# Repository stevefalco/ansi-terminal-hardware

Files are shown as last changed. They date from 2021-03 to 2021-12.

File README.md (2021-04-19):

ANSI Terminal is a "dumb" terminal that emulates part of a VT100.  It is sufficient to use with vi under 2.11bsd, and it also works well as a dumb terminal for Linux.  It successfully allows editing using the "vim" editor.  An M68K (M68000) soft-core processor is contained in an FPGA on a CYC1000 module, and handles all the processing chores.

This project contains IP cores as follows:

https://github.com/ijor/fx68k provides the M68000 processor.

https://opencores.org/projects/a_vhd_16550_uart provides a 16550 compatible uart.

Unlike many existing terminal projects, this project targets 1280x1024 monitors, which are much more common than the 640x480 monitors of days gone by.  This also allows higher quality characters, using 16x32 glyphs, rather than the more common 8x16 glyphs.

The terminal supports both hardware and software flow control, as selected by a dip switch, and baud rates from 110 to 115200 are supported.

This project contains the KiCAD schematic, board layout, gerbers, and a 3-D printable case design.  Note that this is a 2-layer board with surface mount components.

A companion project, https://github.com/stevefalco/ansi-terminal-firmware contains the FPGA and assembly language software for the ANSI Terminal.

Here are photos of the case, pcb, schematic and displayed text.  There is a higher resolution copy of the schematic in file terminal.pdf.

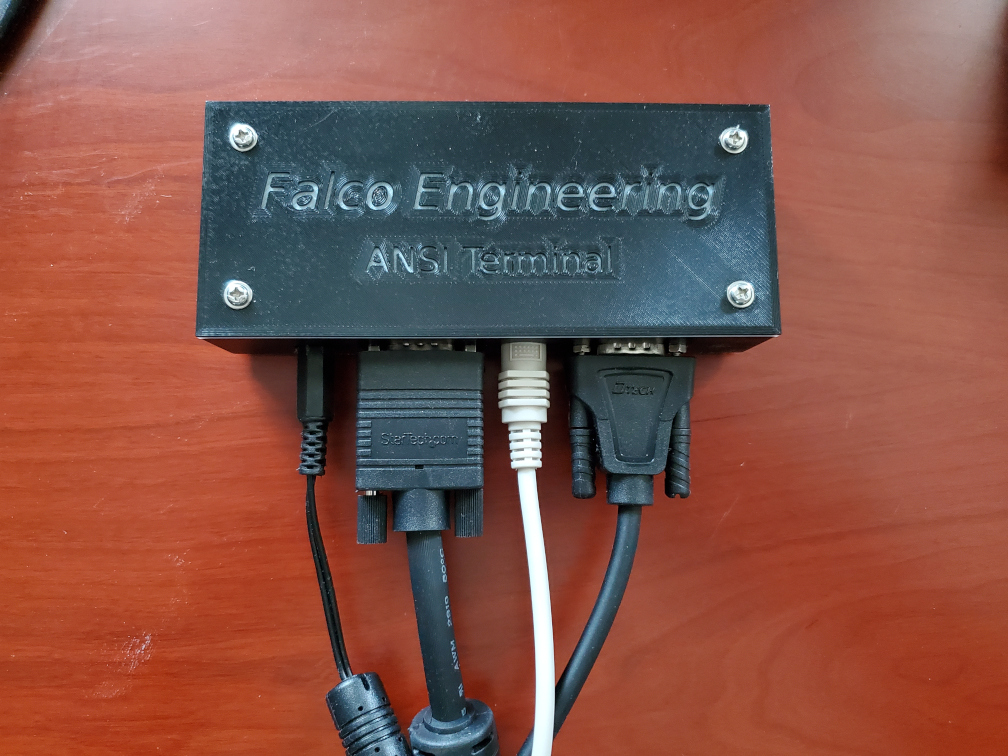
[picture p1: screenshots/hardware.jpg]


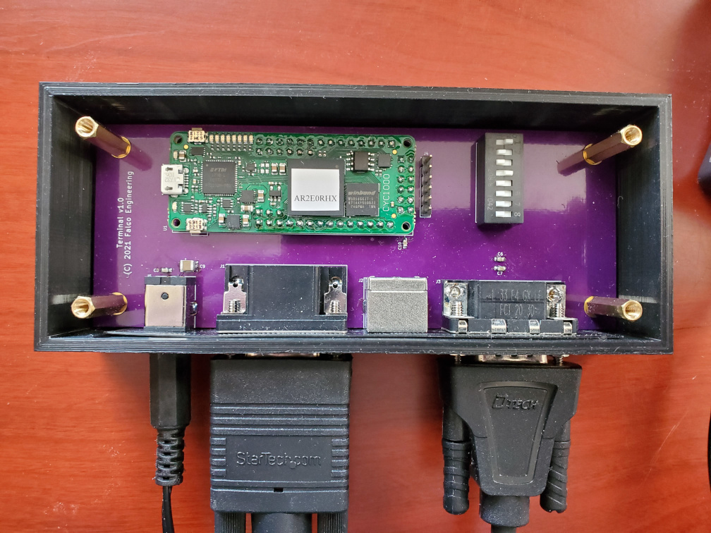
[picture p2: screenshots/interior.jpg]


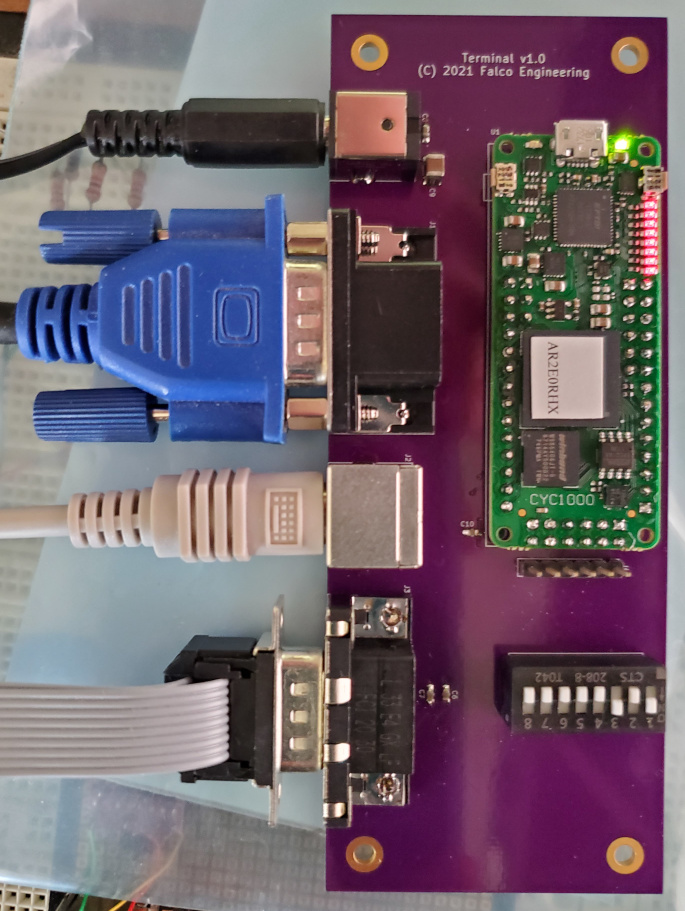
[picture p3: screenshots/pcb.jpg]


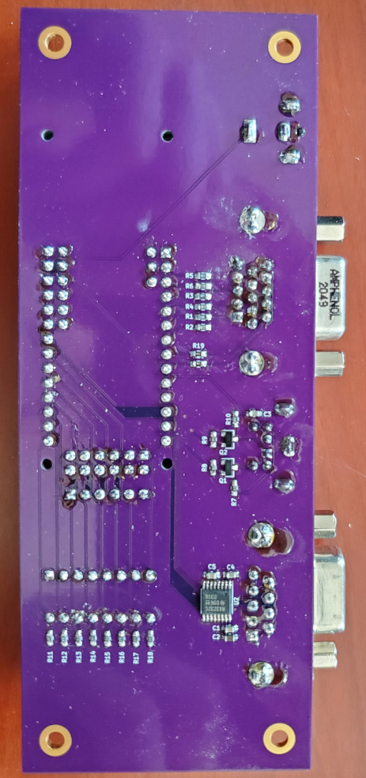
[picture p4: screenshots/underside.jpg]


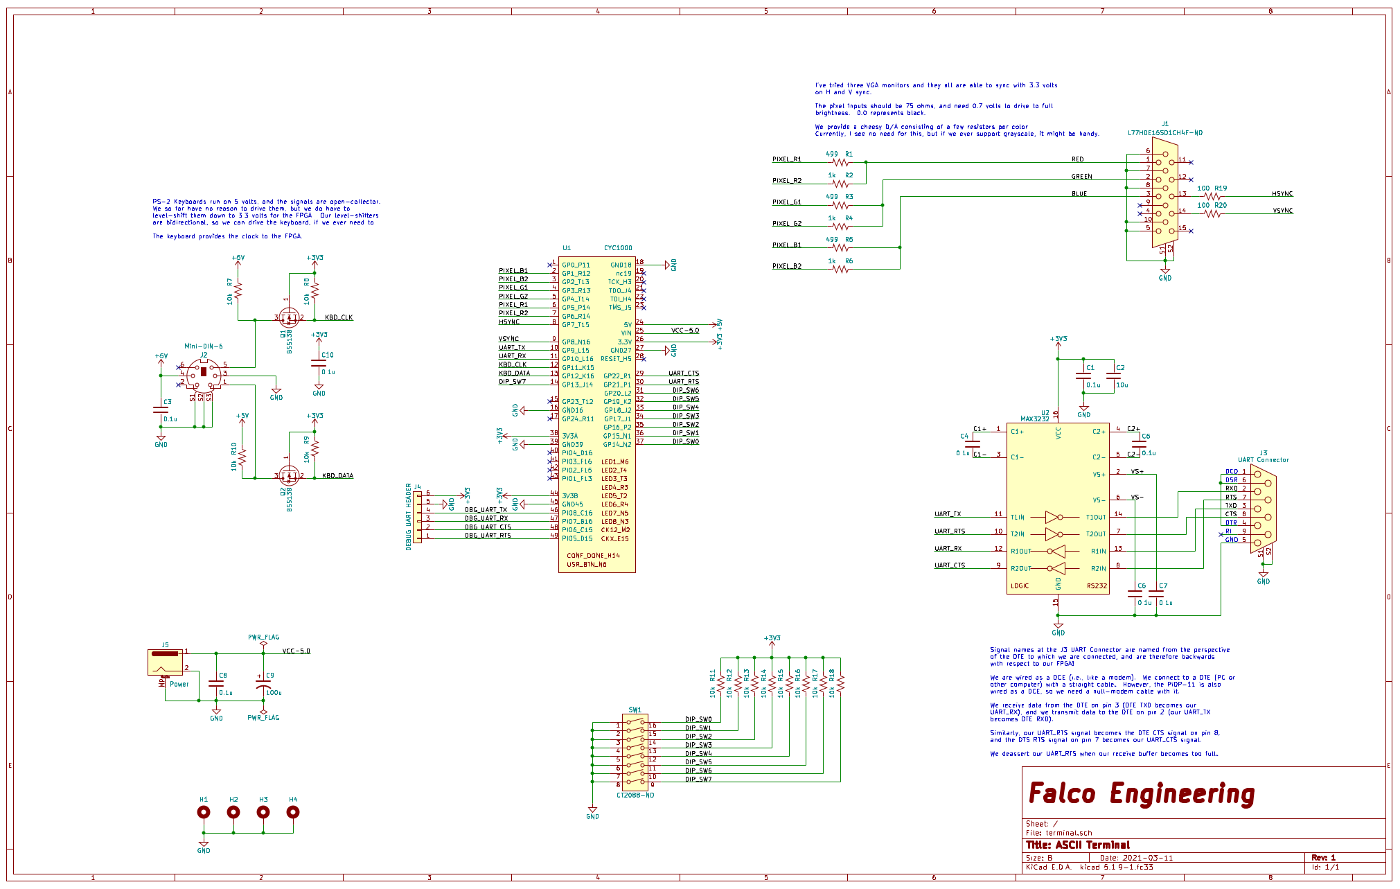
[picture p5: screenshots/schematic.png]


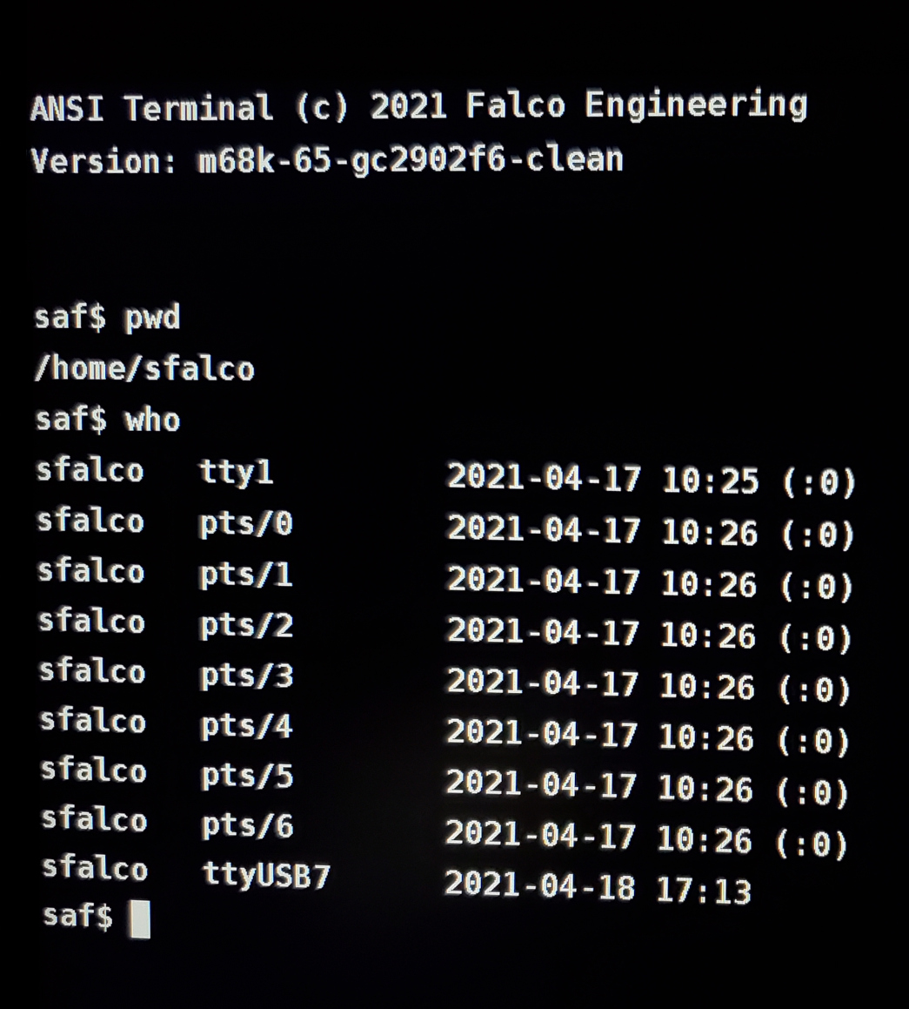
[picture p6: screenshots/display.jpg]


ANSI Terminal

(c) 2021 Steven A. Falco

ANSI Terminal is free software: you can redistribute it and/or modify
it under the terms of the GNU General Public License as published by
the Free Software Foundation, either version 3 of the License, or
(at your option) any later version.

ANSI Terminal is distributed in the hope that it will be useful,
but WITHOUT ANY WARRANTY; without even the implied warranty of
MERCHANTABILITY or FITNESS FOR A PARTICULAR PURPOSE.  See the
GNU General Public License for more details.

You should have received a copy of the GNU General Public License
along with ANSI Terminal.  If not, see <https://www.gnu.org/licenses/>.

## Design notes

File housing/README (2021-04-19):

The housing consists of three parts.  The "bottom" has four holes that are
deliberately slightly under-sized.  You can use either a 2.5 mm or #39
drill to enlarge the holes.  Then use an M3 x 0.5 tap to thread the holes.

The PCB is placed in the bottom housing, and then secured using "M-F"
stand-offs; i.e. stand-offs with one male end and one female end.  The top
cover will later be attached to the female end of the stand-offs.

The "front" is optional.  The idea is that we have cutouts for the various
jacks, but it would be very difficult to produce the thin sections needed with
a typical 3D printer.  Instead, we print a thin piece to go on the inside of
the box - the only purpose this serves is to make the package a bit neater.
It can easily be omitted.

The "top" can be printed in one color, or you can switch to a different
color after layer 4, to make the lettering stand out.

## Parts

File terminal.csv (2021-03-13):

Title | ASCII Terminal
Revision | 1
Date | 2021-03-11
Generated | Sat 13 Mar 2021 14:03:59 EST
Company | Falco Engineering
Comment 1
Comment 2
Comment 3
Comment 4
Total Parts | 44
Total Unique Parts | 17
Ref | Qty | Value | Footprint | Datasheet
C1 C3 C4 C5 C6 C7 C8 C10 | 8 | 0.1u | Capacitor_SMD:C_0603_1608Metric_Pad1.08x0.95mm_HandSolder | ~
C2 | 1 | 10u | Capacitor_SMD:C_0603_1608Metric_Pad1.08x0.95mm_HandSolder | ~
C9 | 1 | 100u | Capacitor_SMD:C_1210_3225Metric_Pad1.33x2.70mm_HandSolder | ~
H1 H2 H3 H4 | 4 | MountingHole_Pad | MountingHole:MountingHole_3.2mm_M3_DIN965_Pad | ~
J1 | 1 | L77HDE15SD1CH4F-ND | falco_terminal:AMPHENOL_L77HDE15SD1CH4F | ~
J2 | 1 | Mini-DIN-6 | falco_terminal:CUI_MD-60SM | http://service.powerdynamics.com/ec/Catalog17/Section%2011.pdf
J3 | 1 | UART Connector | falco_terminal:AMPHENOL_LD09S33E4GX00LF | ~
J4 | 1 | DEBUG UART HEADER | Connector_PinHeader_2.54mm:PinHeader_1x06_P2.54mm_Vertical | ~
J5 | 1 | Power | falco_terminal:BarrelJack_CUI_PJ-063AH_Horizontal | ~
Q1 Q2 | 2 | BSS138 | Package_TO_SOT_SMD:SOT-23 | https://www.onsemi.com/pub/Collateral/BSS138-D.PDF
R1 R3 R5 | 3 | 500 | Resistor_SMD:R_0603_1608Metric_Pad0.98x0.95mm_HandSolder | ~
R2 R4 R6 | 3 | 1k | Resistor_SMD:R_0603_1608Metric_Pad0.98x0.95mm_HandSolder | ~
R7 R8 R9 R10 R11 R12 R13 R14 R15 R16 R17 R18 | 12 | 10k | Resistor_SMD:R_0603_1608Metric_Pad0.98x0.95mm_HandSolder | ~
R19 R20 | 2 | 100 | Resistor_SMD:R_0603_1608Metric_Pad0.98x0.95mm_HandSolder | ~
SW1 | 1 | CT2088-ND | Package_DIP:DIP-16_W7.62mm_Socket | ~
U1 | 1 | CYC1000 | falco_CYC1000:CYC1000
U2 | 1 | MAX3232 | falco_terminal:TSSOP-16_4.4x5mm_P0.65mm | https://datasheets.maximintegrated.com/en/ds/MAX3222-MAX3241.pdf
BOM made with KICAD_BOM_WIZARD (https://github.com/HashDefineElectronics/KiCad_BOM_Wizard.git)
Generated Sat 13 Mar 2021 14:03:59 EST

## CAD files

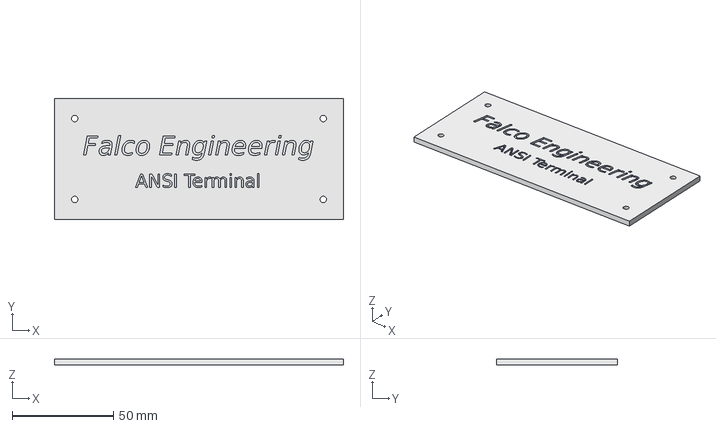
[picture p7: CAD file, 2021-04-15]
housing/top.FCStd
143.0 x 60.0 x 3.00 mm

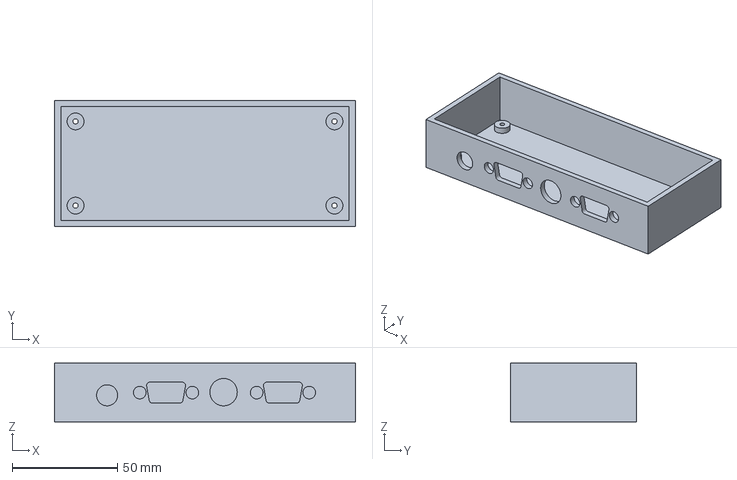
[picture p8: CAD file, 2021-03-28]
housing/CE3PRO_bottom.3mf
143.0 x 60.0 x 28.0 mm

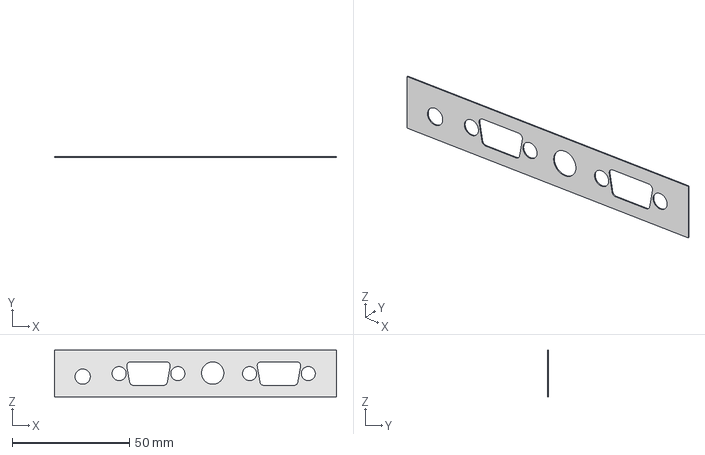
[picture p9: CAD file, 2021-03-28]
housing/front.FCStd
120.0 x 0.4 x 20.0 mm

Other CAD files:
housing/CE3PRO_top.3mf
housing/CE3PRO_front.3mf
housing/bottom.FCStd
housing/bottom.stl
housing/front.stl
housing/top.stl

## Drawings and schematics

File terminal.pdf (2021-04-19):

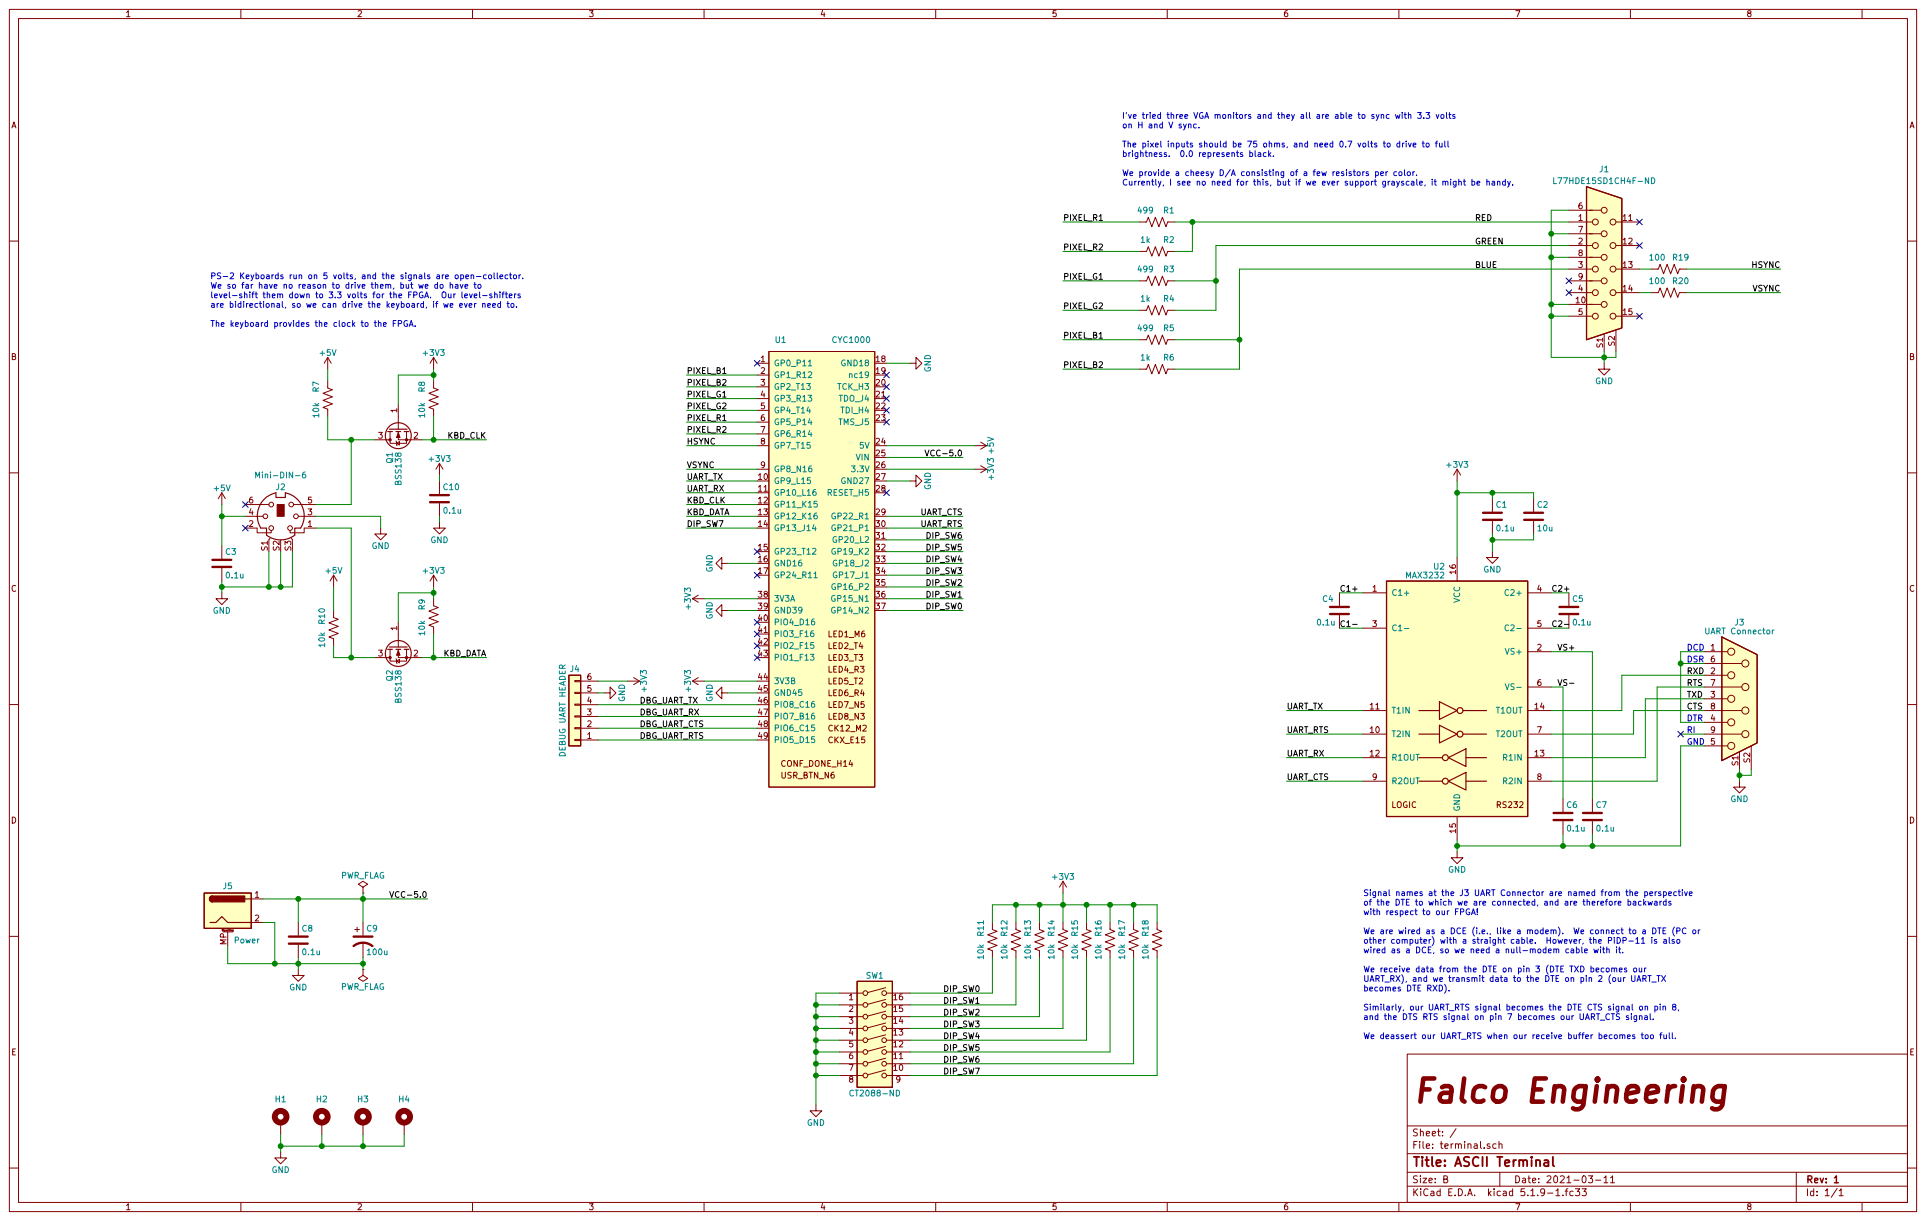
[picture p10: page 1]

I've tried three VGA monitors and they all are able to sync with 3.3 volts
on H and V sync.

The pixel inputs should be 75 ohms, and need 0.7 volts to drive to full
brightness. 0.0 represents black.

We provide a cheesy D/A consisting of a few resistors per color.
Currently, I see no need for this, but if we ever support grayscale, it might be handy.

PS-2 Keyboards run on 5 volts, and the signals are open-collector. We so far have no reason to drive them, but we do have to

level-shift them down to 3.3 volts for the FPGA. Our level-shifters are bidirectional, so we can drive the keyboard, if we ever need to.

Id: 1/1 Title: ASCII Terminal File: terminal.sch Sheet: / Falco Engineering 123456

Signal names at the J3 UART Connector are named from the perspective
of the DTE to which we are connected, and are therefore backwards with respect to our FPGA!

We are wired as a DCE (i.e., like a modem). We connect to a DTE (PC or
other computer) with a straight cable. However, the PiDP-11 is also wired as a DCE, so we need a null-modem cable with it. We receive data from the DTE on pin 3 (DTE TXD becomes our

UART_RX), and we transmit data to the DTE on pin 2 (our UART_TX
becomes DTE RXD).

Similarly, our UART_RTS signal becomes the DTE CTS signal on pin 8,
and the DTS RTS signal on pin 7 becomes our UART_CTS signal. We deassert our UART_RTS when our receive buffer becomes too full.

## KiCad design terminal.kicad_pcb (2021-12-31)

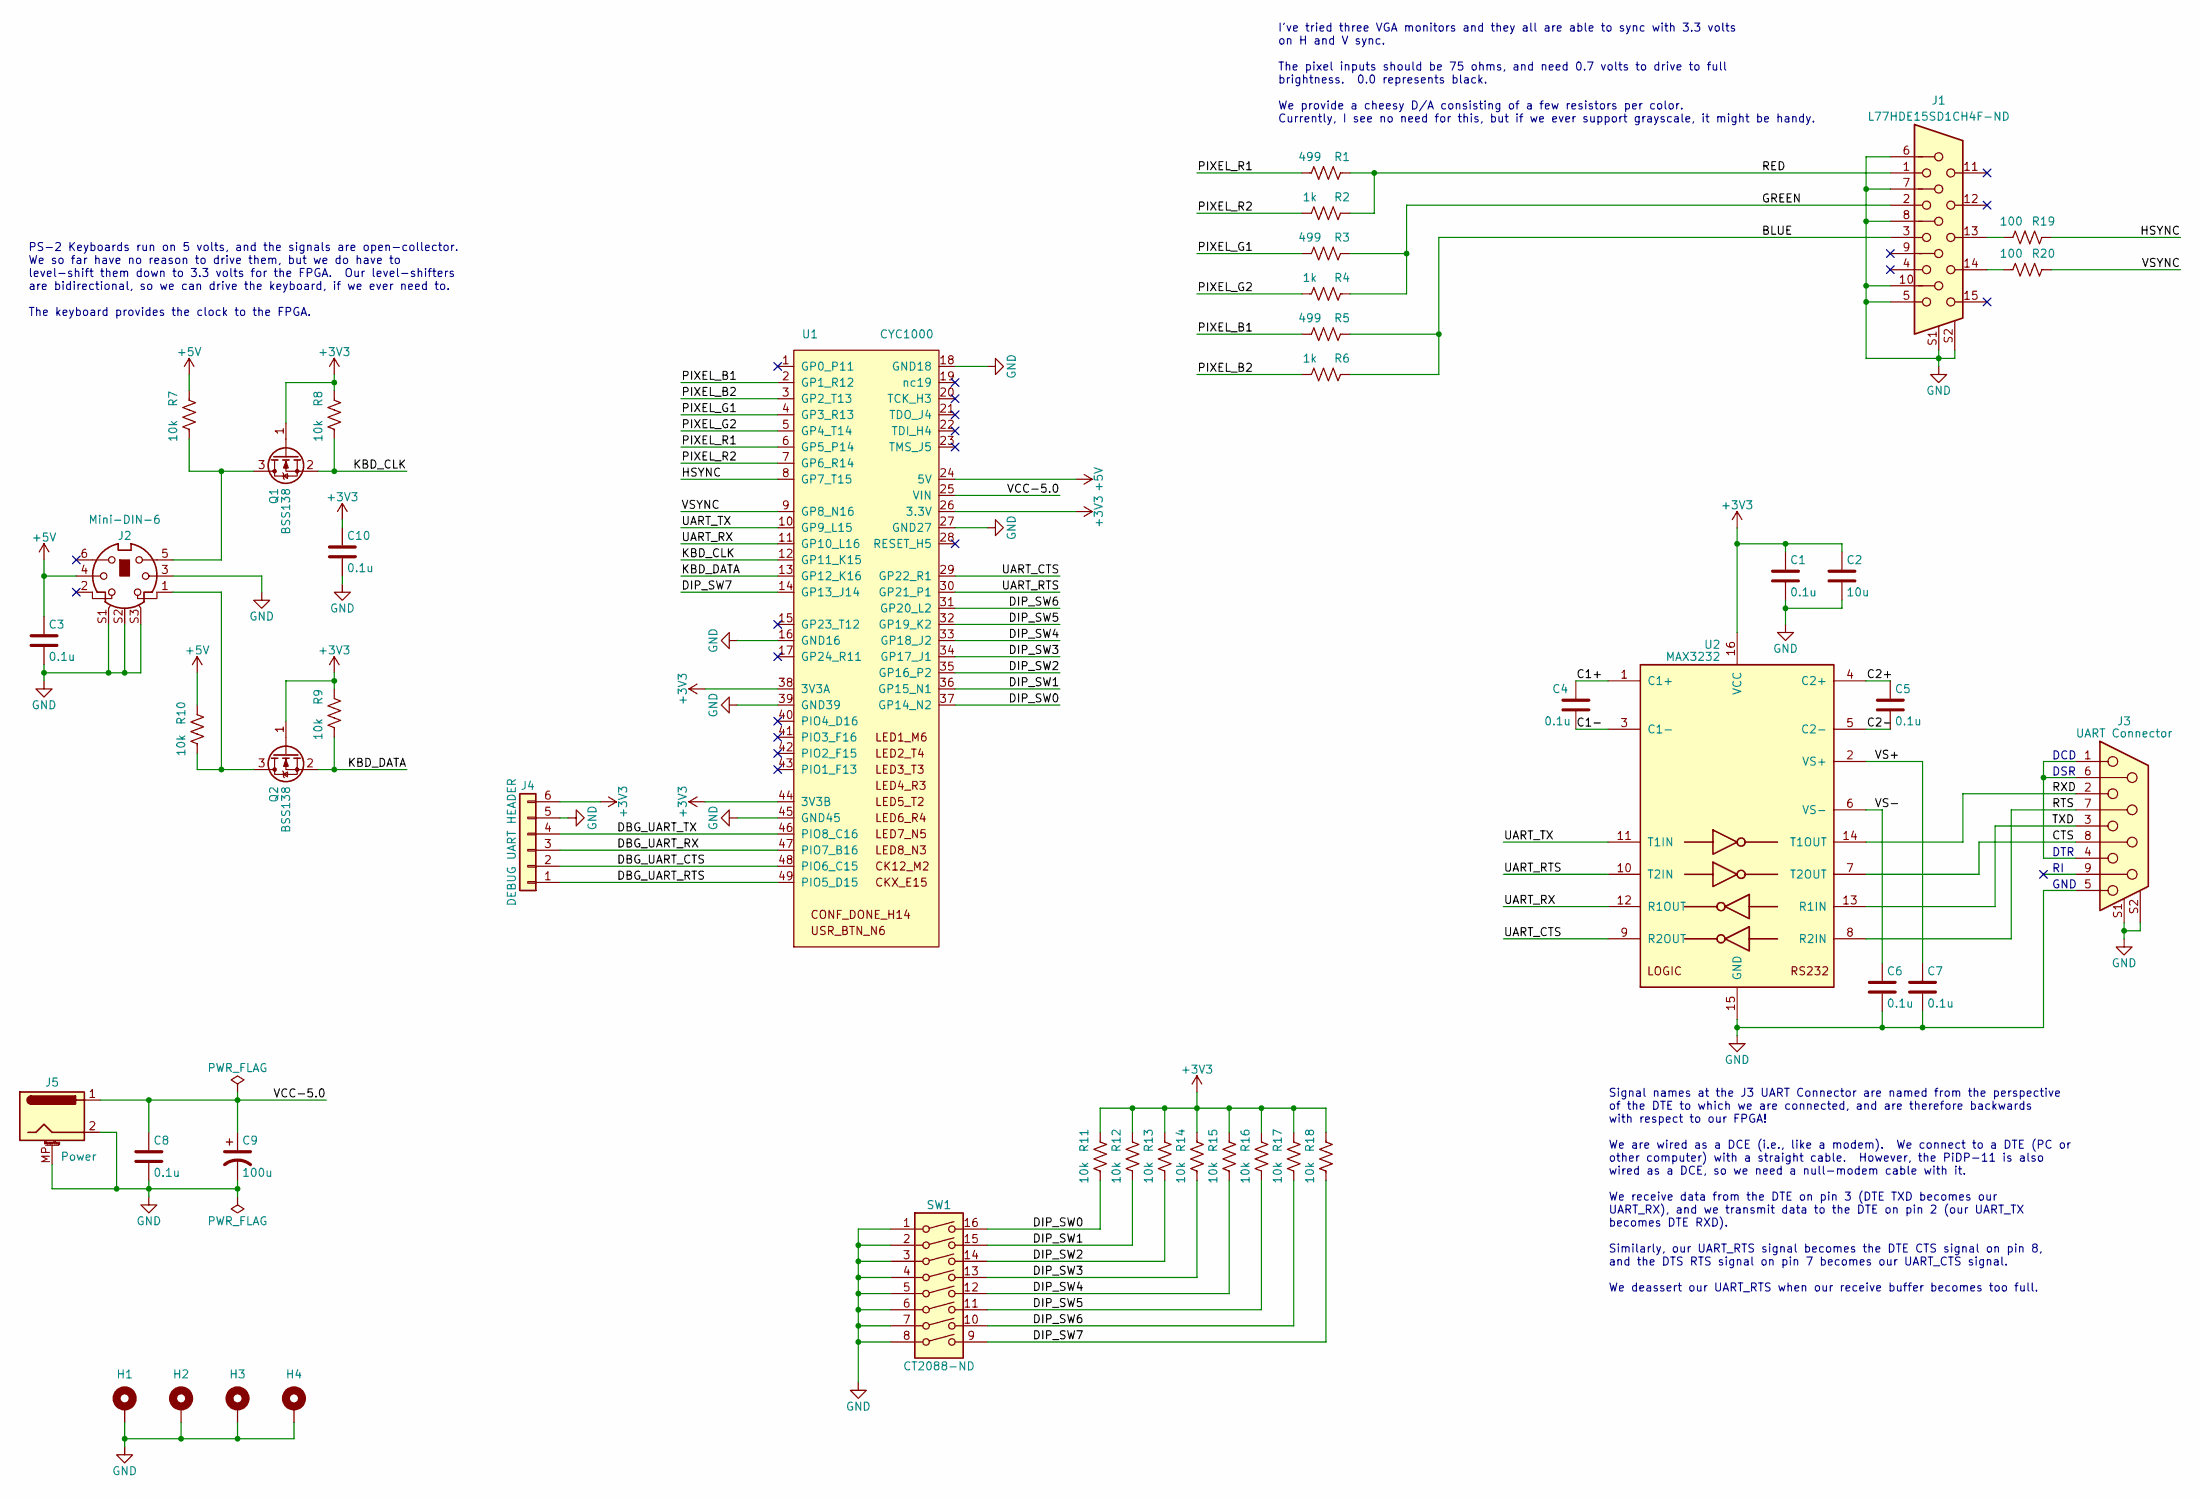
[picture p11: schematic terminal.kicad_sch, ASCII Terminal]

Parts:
C1, C3, C4, C5, C6, C7, C8, C10: 0.1u; C_0603_1608Metric_Pad1.08x0.95mm_HandSolder
C2: 10u; C_0603_1608Metric_Pad1.08x0.95mm_HandSolder
C9: 100u; C_1210_3225Metric_Pad1.33x2.70mm_HandSolder
H1, H2, H3, H4: MountingHole_Pad; MountingHole_3.2mm_M3_DIN965_Pad
J1: L77HDE15SD1CH4F-ND; AMPHENOL_L77HDE15SD1CH4F
J2: Mini-DIN-6; CUI_MD-60SM
J3: UART Connector; AMPHENOL_LD09S33E4GX00LF
J4: DEBUG UART HEADER; PinHeader_1x06_P2.54mm_Vertical
J5: Power; BarrelJack_CUI_PJ-063AH_Horizontal
Q1, Q2: BSS138; SOT-23
R1, R3, R5: 499; R_0603_1608Metric_Pad0.98x0.95mm_HandSolder
R2, R4, R6: 1k; R_0603_1608Metric_Pad0.98x0.95mm_HandSolder
R7, R8, R9, R10, R11, R12, R13, R14, R15, R16, R17, R18: 10k; R_0603_1608Metric_Pad0.98x0.95mm_HandSolder
R19, R20: 100; R_0603_1608Metric_Pad0.98x0.95mm_HandSolder
SW1: CT2088-ND; DIP-16_W7.62mm_Socket
U1: CYC1000
U2: MAX3232; TSSOP-16_4.4x5mm_P0.65mm

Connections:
+3V3: C1.1, C2.1, C10.1, J4.6, Q1.1 (G), Q2.1 (G), R8.1, R9.1, R11.1, R12.1, R13.1, R14.1, R15.1, R16.1, R17.1, R18.1, U1.26 (3.3V), U1.38 (3V3A), U1.44 (3V3B), U2.16 (VCC)
+5V: C3.1, J2.4, R7.1, R10.1, U1.24 (5V)
/BLUE: J1.3, R5.1, R6.1
/C1+: C4.1, U2.1 (C1+)
/C1-: C4.2, U2.3 (C1-)
/C2+: C5.1, U2.4 (C2+)
/C2-: C5.2, U2.5 (C2-)
/CTS: J3.8, U2.7 (T2OUT)
/DBG_UART_CTS: J4.2, U1.48 (PIO6_C15)
/DBG_UART_RTS: J4.1, U1.49 (PIO5_D15)
/DBG_UART_RX: J4.3, U1.47 (PIO7_B16)
/DBG_UART_TX: J4.4, U1.46 (PIO8_C16)
/DIP_SW0: R11.2, SW1.16, U1.37 (GP14_N2)
/DIP_SW1: R12.2, SW1.15, U1.36 (GP15_N1)
/DIP_SW2: R13.2, SW1.14, U1.35 (GP16_P2)
/DIP_SW3: R14.2, SW1.13, U1.34 (GP17_J1)
/DIP_SW4: R15.2, SW1.12, U1.33 (GP18_J2)
/DIP_SW5: R16.2, SW1.11, U1.32 (GP19_K2)
/DIP_SW6: R17.2, SW1.10, U1.31 (GP20_L2)
/DIP_SW7: R18.2, SW1.9, U1.14 (GP13_J14)
/GREEN: J1.2, R3.1, R4.1
/HSYNC: R19.1, U1.8 (GP7_T15)
/KBD_CLK: Q1.2 (S), R8.2, U1.12 (GP11_K15)
/KBD_DATA: Q2.2 (S), R9.2, U1.13 (GP12_K16)
/PIXEL_B1: R5.2, U1.2 (GP1_R12)
/PIXEL_B2: R6.2, U1.3 (GP2_T13)
/PIXEL_G1: R3.2, U1.4 (GP3_R13)
/PIXEL_G2: R4.2, U1.5 (GP4_T14)
/PIXEL_R1: R1.2, U1.6 (GP5_P14)
/PIXEL_R2: R2.2, U1.7 (GP6_R14)
/RED: J1.1, R1.1, R2.1
/RTS: J3.7, U2.8 (R2IN)
/RXD: J3.2, U2.14 (T1OUT)
/TXD: J3.3, U2.13 (R1IN)
/UART_CTS: U1.29 (GP22_R1), U2.9 (R2OUT)
/UART_RTS: U1.30 (GP21_P1), U2.10 (T2IN)
/UART_RX: U1.11 (GP10_L16), U2.12 (R1OUT)
/UART_TX: U1.10 (GP9_L15), U2.11 (T1IN)
/VCC-5.0: C8.1, C9.1, J5.1, U1.25 (VIN)
/VS+: C7.1, U2.2 (VS+)
/VS-: C6.1, U2.6 (VS-)
/VSYNC: R20.1, U1.9 (GP8_N16)
GND: C1.2, C2.2, C3.2, C6.2, C7.2, C8.2, C9.2, C10.2, H1.1, H2.1, H3.1, H4.1, J1.5, J1.6, J1.7, J1.8, J1.10, J1.S1, J1.S2, J2.3, J2.S1, J2.S2, J2.S3, J3.5, J3.S1, J3.S2, J4.5, J5.2, J5.MP (MountPin), SW1.1, SW1.2, SW1.3, SW1.4, SW1.5, SW1.6, SW1.7, SW1.8, U1.16 (GND16), U1.18 (GND18), U1.27 (GND27), U1.39 (GND39), U1.45 (GND45), U2.15 (GND)
unnamed: J1.13, R19.2
unnamed: J1.14, R20.2
unnamed: J2.1, Q2.3 (D), R10.2
unnamed: J2.5, Q1.3 (D), R7.2
unnamed: J3.1, J3.4, J3.6

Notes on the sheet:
GND
Signal names at the J3 UART Connector are named from the perspective of the DTE to which we are connected, and are therefore backwards with respect to our FPGA! We are wired as a DCE (i.e., like a modem). We connect to a DTE (PC or other computer) with a straight cable. However, the PiDP-11 is also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
DTR
I've tried three VGA monitors and they all are able to sync with 3.3 volts on H and V sync. The pixel inputs should be 75 ohms, and need 0.7 volts to drive to full brightness. 0.0 represents black. We provide a cheesy D/A consisting of a few resistors per color. Currently, I see no need for this, b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
PS-2 Keyboards run on 5 volts, and the signals are open-collector. We so far have no reason to drive them, but we do have to level-shift them down to 3.3 volts for the FPGA. Our level-shifters are bidirectional, so we can drive the keyboard, if we ever need to. The keyboard provides the clock to th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
DCD
DSR

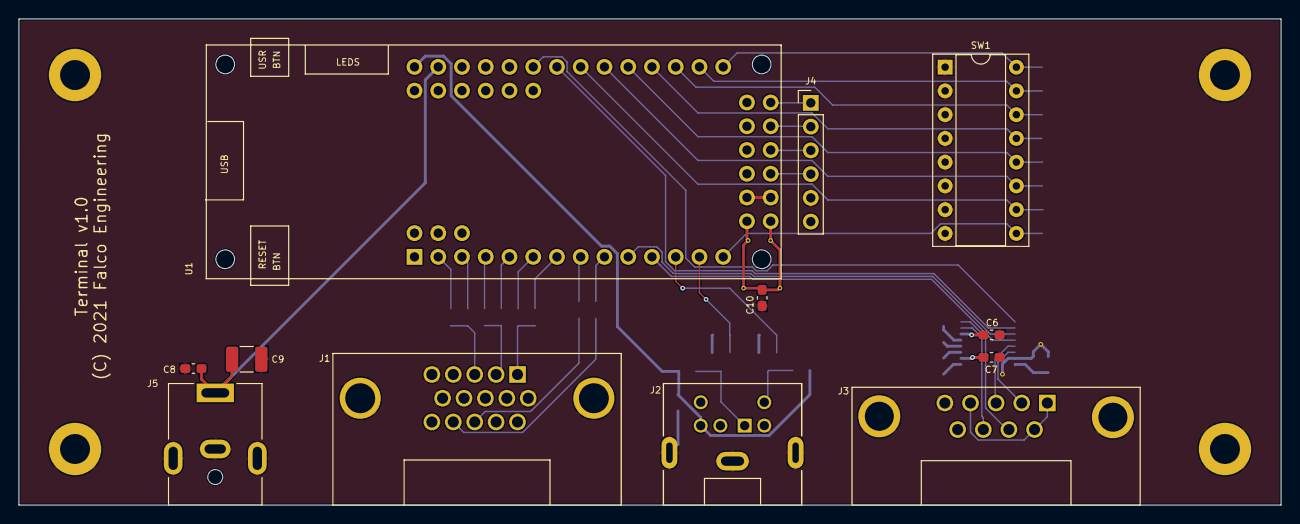
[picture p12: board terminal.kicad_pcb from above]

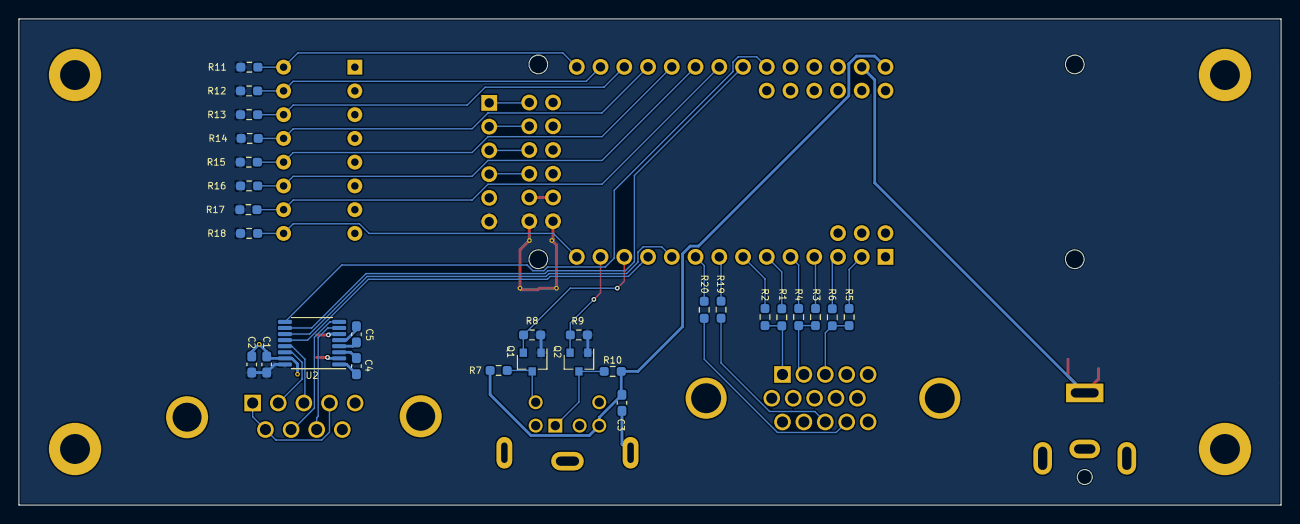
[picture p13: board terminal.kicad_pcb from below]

Board: 2 copper layers, 135.0 x 52.0 mm, 44 parts (28 on the bottom side), 48 nets.

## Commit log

2021-03-11 Schematic complete
2021-03-12 Starting layout
    [terminal.sch]
2021-03-12 Wiring connectors
    [terminal.kicad_pcb, terminal.sch]
2021-03-12 Should be pretty close
    [terminal.kicad_pcb, terminal.sch]
2021-03-13 V1 looks good
    [terminal-B_Cu.gbl, terminal-B_Mask.gbs, terminal-B_Paste.gbp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]
2021-03-13 Add BOM
    [terminal.csv]
2021-03-16 Sense of RX/TX and CTS/RTS were backwards.
    Fortunately, that is easy to fix in the FPGA by remapping the signals to
    different pins.
    [terminal-B_Cu.gbl, terminal-B_Mask.gbs, terminal-B_Paste.gbp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]
2021-03-26 Fix R values & silk
    [terminal.kicad_pcb, terminal.sch]
2021-03-28 Add housing
    [CE3PRO_bottom.3mf, CE3PRO_front.3mf, CE3PRO_top.3mf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]
2021-04-15 Housing update
    [CE3PRO_top.3mf, top.FCStd, top.stl]
2021-04-19 Add schematic pdf
2021-11-21 Convert to KiCad 6 series
    [terminal.kicad_pcb, terminal.kicad_sch]
2021-11-24 Move to KiCad 6
2021-12-31 Move template file
    [terminal.kicad_pcb]

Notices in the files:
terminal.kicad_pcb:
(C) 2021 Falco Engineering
